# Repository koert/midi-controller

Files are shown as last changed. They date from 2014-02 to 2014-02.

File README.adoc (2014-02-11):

== DIY Midi controller

This is a project to create a custom MIDI controller based on:

* Teensy 3.1
* Pressure sensitive buttons made with anti static foam
* WS2812B LED's
* Nokia 5110 LCD display

=== Resources

==== Teensy
Website: http://www.pjrc.com/teensy
Shop: http://floris.cc/shop/en/8-teensy

==== LCD display
https://www.sparkfun.com/products/10168

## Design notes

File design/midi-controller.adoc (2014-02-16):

== Midi controller

=== Todo

* connect LED's, display pushed button
* buttons for octave up/down

=== Done

* design schematic pressure button in 4x4 matrix
* mount buttons on PCB
* display notes on LCD display
* note on/off with velocity
* pushbutton prototype - connect to Arduino
* send midi note to computer via Serial

=== Inspiration

http://jazarimusic.com/finally-a-diy-midi-controller-with-purpleheart/

==== Velocity and aftertouch

[quote, http://www.codetinkerhack.com/2013/01/how-to-add-velocity-aftertouch-midi.html]
____
1) Measuring Velocity sensitivity required to add timing mechanism to allow sufficient time to read the FSR sensor as Note will get pressed first and FSR sensor second. So before we can send the note we need to measure the FSR values. To implement this two arrays were introduced: one  remembers the Note that was pressed and acts as a buffer: noteChannelPressed and second remembers the milliseconds when the note was pressed: previousMillisChannel. After a delay of about 1 ms value of FSR is translated to a volume. (currently linear translation is done by simple mapping the range of FSR  to MIDI but you can experiment and see what suits most your FSR/location/mechanics, etc). And after that note with volume is sent to Midi. The functions implementing above are getNote() and sendChannelNotes()

2) Aftertouch was implemented (as well) based on FSR readings and handled by sendChannelExpression(). Effect is only kicks in after 1 second which is configured in expressionDelay constant. As aftertouch effect I've used midi modulation command as it is widely supported by all synth. It can be map to any other effect that your synth support.
____

=== Hardware

==== Multiplexer

http://www.conrad.nl/ce/nl/product/155668/Logic-IC-STMicroelectronics-HCF-4051-BEY-Soort-behuizing-DIP-16-Uitvoering-Multiplexer
3 bit selector for 8 in/out

http://www.conrad.nl/ce/nl/product/173320/CMOS-IC-Texas-Instruments-4067-Soort-behuizing-DIP-24-Uitvoering-Multiplexerdemultiplexer-16-analogedigitale-kanalen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
4 bit selector for 16 in/out

==== Other

Arduino Leonardo

* http://www.conrad.nl/ce/nl/product/046518/Arduino-Leonardo-incl-USB-kabel?ref=list
* https://www.youtube.com/watch?v=aaGbciiM_G0
* https://iprototype.nl/products/arduino/boards/leonardo-no-headers

LED  WS2812

* http://mikrocontroller-praxis.de/de/Display-Optoelektronik/LED/LED-RGB/WS2812-5050-RGB-LED-with-Integrated-Driver-Chip-1PCS.html

LED  WS2812B

* http://www.aliexpress.com/item/WS2812B-4pins-5050-SMD-W-WS2811-Individually-Addressable-Digital-RGB-LED-Chip/1416686122.html

Teensy

* http://www.pjrc.com/teensy/
* http://floris.cc/shop/en/8-teensy

Buttons

* https://www.sparkfun.com/products/7835

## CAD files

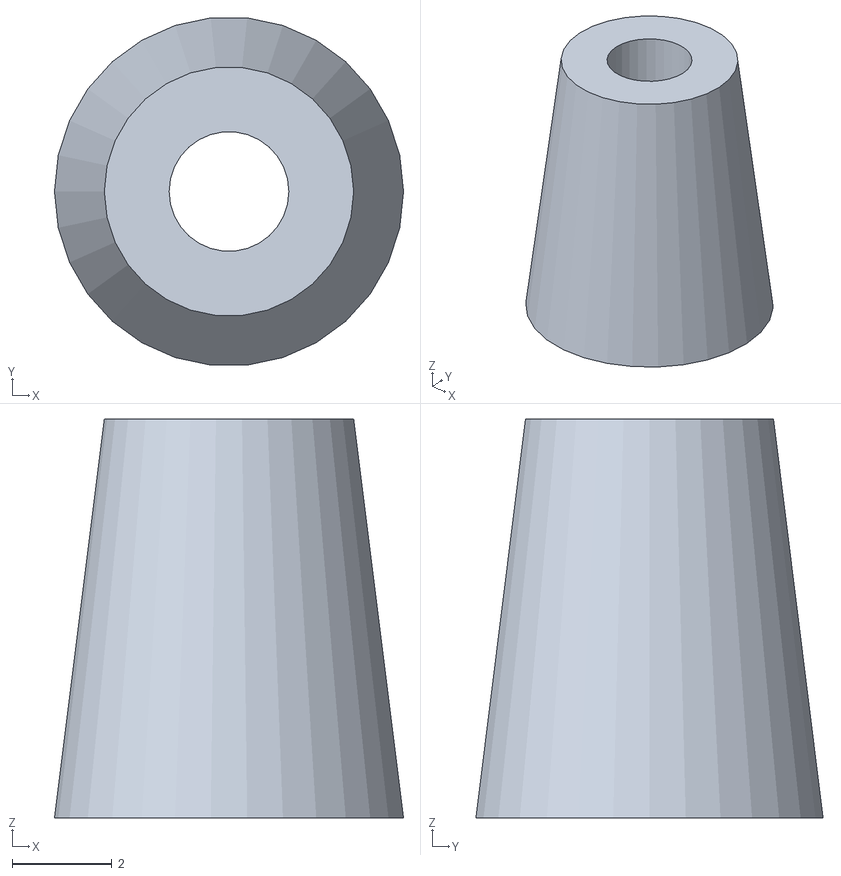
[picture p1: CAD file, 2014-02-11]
design/button-foam4.stl
7.00 x 6.96 x 8.00

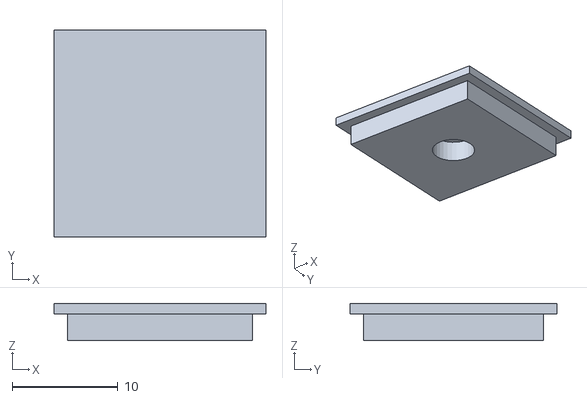
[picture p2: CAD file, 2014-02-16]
design/switch-foam-combo/button-grid-top.stl
20.0 x 19.5 x 3.50

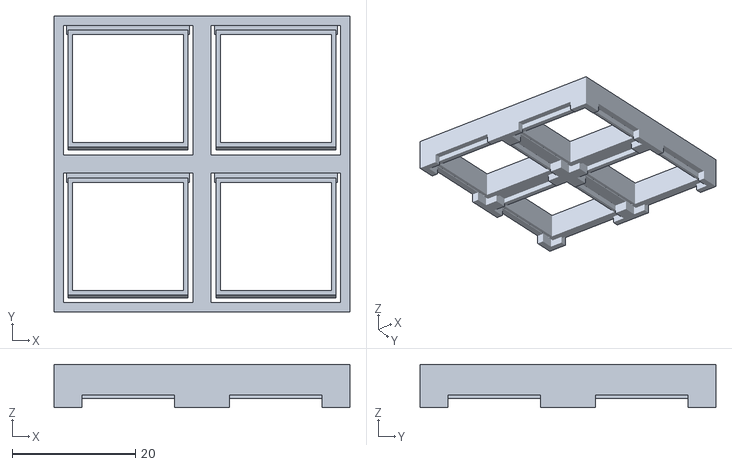
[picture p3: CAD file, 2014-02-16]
design/switch-foam-combo/button-grid.stl
48.0 x 48.0 x 7.00

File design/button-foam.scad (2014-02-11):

outerSize = 20;
innerSize = 18;
topHeight = 4;
baseHeight = 5;
foamWidth = 5;
foamHeight = 1.0;
spaceY = 2;
thickness = 1;
margin = 1.2;
tightMargin = 0.5;

module top() {
  $fn=100;
  $fs=1;
  translate([0, 0, baseHeight + spaceY])
  difference() {
    translate([0, 0, topHeight/2])
    cube([outerSize, outerSize, topHeight], center=true);
    translate([0, 0, topHeight/2-thickness])
    cube([innerSize, innerSize, topHeight], center=true);
  }

}

module base() {
  $fn=100;
  $fs=1;
  translate([0, 0, baseHeight/2])
  difference() {
    translate([0, 0, 0])
    cube([outerSize, outerSize, baseHeight], center=true);
    translate([0, 0, 0])
    cube([innerSize, innerSize, baseHeight+1], center=true);
  }

}

module buttonTop() {
  $fn=100;
  $fs=1;
  innerHeight = baseHeight - foamHeight - tightMargin;
  translate([0, 0, thickness])
  union() {
    translate([0, 0, thickness/2])
    cube([outerSize, outerSize, thickness], center=true);
    translate([0, 0, -innerHeight/2])
    cube([innerSize-tightMargin, innerSize-tightMargin, innerHeight], center=true);
  }
}

module buttonBottom() {
  $fn=100;
  $fs=1;
  height = baseHeight;
  innerHeight = baseHeight - foamHeight + margin;  
  translate([0, 0, 0])
  difference() {
    union() {
      translate([0, 0, baseHeight/2])
      cube([outerSize, outerSize, baseHeight], center=true);
      translate([0, 0, thickness+thickness/2])
      cube([outerSize/2, outerSize+thickness, thickness], center=true);
      translate([0, 0, thickness+thickness/2])
      cube([outerSize+thickness, outerSize/2, thickness], center=true);
    }
    translate([0, innerSize/2-foamWidth/2, height/2])
    cube([innerSize, foamWidth, height+thickness+1], center=true);
    translate([0, -innerSize/2+foamWidth/2, height/2])
    cube([innerSize, foamWidth, height+thickness+1], center=true);
    translate([0, 0, height/2])
    cube([innerSize, innerSize-foamWidth*2-thickness*2, height+thickness+1], center=true);
    translate([0, 0, innerHeight/2+foamHeight])
    cube([innerSize, innerSize, innerHeight+0.01], center=true);
  }

}

module buttonMountInner(innerWidth, width, height) {
  innerWidth2 = innerWidth + thickness + margin;
    union() {
	    translate([0, 0, height/2])
	    cube([innerWidth, innerWidth, height+1], center=true);
	    #translate([0, 0, thickness*2])
	    cube([innerWidth2, outerSize/2 + margin, thickness*4], center=true);
	    translate([0, 0, thickness*2])
	    cube([outerSize/2 + margin, innerWidth2, thickness*4], center=true);
	    translate([0, 0, thickness-0.5])
	    cube([innerWidth-thickness*2, width+1, thickness*2], center=true);
	    translate([0, 0, thickness-0.5])
	    cube([width+1, innerWidth-thickness*2, thickness*2], center=true);
    }
}

module buttonMount() {
  width = outerSize + thickness*6;
  spacing = 2.0;
  totalWidth = outerSize*2 + spacing*4;
  height = baseHeight;
  innerWidth = outerSize + margin;
  innerWidth2 = outerSize + thickness*2 + margin;
  translate([0, 0, -thickness*4])
  difference() {
    translate([0, 0, height/2])
    cube([totalWidth, totalWidth, height], center=true);

    translate([outerSize/2+spacing, outerSize/2+spacing, 0])
    buttonMountInner(innerWidth, width, height);

    translate([-outerSize/2-spacing, outerSize/2+spacing, 0])
    buttonMountInner(innerWidth, width, height);

    translate([outerSize/2+spacing, -outerSize/2-spacing, 0])
    buttonMountInner(innerWidth, width, height);

    translate([-outerSize/2-spacing, -outerSize/2-spacing, 0])
    buttonMountInner(innerWidth, width, height);
  }
}

module bottomSupport() {
  $fn = 30;
  difference() {
    cylinder(h = 8, r1 = 3.5, r2 = 2.5, center = true);
    cylinder(h = 9, r = 1.2, center = true);
  }
}

*top();
*base();

*buttonTop();

*translate([0, 0, -10])
buttonBottom();

*translate([45, 0, -10])
buttonMount();

translate([0, 0, -10])
bottomSupport();

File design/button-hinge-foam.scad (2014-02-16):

capOuterWidth = 20;
capOuterHeight = 7;
buttonMargin = 2;
holeRadius = 5/2;
holeHeight = 2.5;
wallThickness = 1;
tightMargin = 0.5;
margin = 1;
foamWidth = 5;
foamHeight = 1.0;

module capTop() {
  $fn = 30;
  innerWidth = capOuterWidth - wallThickness*2 - tightMargin;
  ceilingHeight = holeHeight;
  //translate([0, 0, capOuterHeight/2])
  union() {
    translate([0, 0, ceilingHeight/2+wallThickness/2])
    cube([capOuterWidth, capOuterWidth-wallThickness/2, wallThickness], center=true);
    translate([0, 0, 0])
    difference() {
      cube([innerWidth, innerWidth-wallThickness/2, ceilingHeight], center=true);
      translate([0, 0, holeHeight-margin/2-ceilingHeight])
      cylinder(h = holeHeight+margin, r = holeRadius, center = true);
    }
  }
}


module inner(innerWidth) {
  union() {
    translate([0, 0, 0])
    cube([innerWidth, innerWidth, capOuterHeight+margin], center=true);

    translate([0, 0, -capOuterHeight+wallThickness*2])
    cube([capOuterWidth*0.75, capOuterWidth+wallThickness*5, capOuterHeight], center=true);
    translate([0, 0, -capOuterHeight+wallThickness*2])
    cube([capOuterWidth+wallThickness*5, capOuterWidth*0.75, capOuterHeight], center=true);
  }
}


module grid() {
  $fn = 30;
  buttonGridSize = capOuterWidth + buttonMargin*2;
  gridWidth = buttonGridSize * 2;
  gridHeight = buttonGridSize * 2;
  innerWidth = capOuterWidth + margin;
  ceilingHeight = holeHeight + wallThickness;
  union() {
	  translate([0, 0, capOuterHeight/2])
	  difference() {
	    translate([0, 0, 0])
	    cube([gridWidth, gridWidth, capOuterHeight], center=true);
	
	    translate([-buttonGridSize/2, buttonGridSize/2, 0])
	    inner(innerWidth);
	    translate([buttonGridSize/2, buttonGridSize/2, 0])
	    inner(innerWidth);
	    translate([-buttonGridSize/2, -buttonGridSize/2, 0])
	    inner(innerWidth);
	    translate([buttonGridSize/2, -buttonGridSize/2, 0])
	    inner(innerWidth);
	 }

    translate([-buttonGridSize/2, buttonGridSize/2, 0])
    capBottom();

    translate([buttonGridSize/2, buttonGridSize/2, 0])
    capBottom();

    translate([-buttonGridSize/2, -buttonGridSize/2, 0])
    capBottom();

    translate([buttonGridSize/2, -buttonGridSize/2, 0])
    capBottom();
 }
}

module capBottom() {
  $fn = 30;
  size = capOuterWidth-tightMargin;
  innerWidth = capOuterWidth - wallThickness*2;
  height = capOuterHeight - wallThickness - tightMargin;
  translate([0, 0, capOuterHeight-height/2])
  difference() {
    union() {
      translate([0, -size/2, -height/2])
      rotate(a = [90, 0, 90])
      linear_extrude(height = size, center = true)
      polygon([[0,height/4],[size,0],[size,height], [wallThickness, height]], convexity = N);

      translate([0, capOuterWidth/2, -height/2+wallThickness/2])
      cube([capOuterWidth, wallThickness*2, wallThickness], center=true);
    }
    translate([0, wallThickness/2, 0])
    cube([innerWidth, innerWidth-wallThickness/2, height+margin], center=true);
  }
}

intersection() {
//translate([-3, -3, 0])
//cube([capOuterWidth*1.5, capOuterWidth*1.5, capOuterHeight*2]);

translate([0, 0, 0])
grid();
}

*translate([0, 0, 20])
capTop();

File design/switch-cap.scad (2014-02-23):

capOuterWidth = 20;
capOuterHeight = 7;
holeRadius = 3.5/2;
holeHeight = 2.5;
wallThickness = 1;
tightMargin = 0.5;
margin = 1;

module cap() {
  $fn = 30;
  innerWidth = capOuterWidth - wallThickness;
  ceilingHeight = holeHeight + wallThickness;
  translate([0, 0, capOuterHeight/2])
  difference() {
    translate([0, 0, 0])
    cube([capOuterWidth, capOuterWidth, capOuterHeight], center=true);
    translate([0, 0, -ceilingHeight])
    cube([innerWidth, innerWidth, capOuterHeight], center=true);
    translate([0, 0, capOuterHeight/2-ceilingHeight+holeHeight/2])
    cylinder(h = holeHeight+1, r = holeRadius, center = true);
  }
}

module capTop() {
  $fn = 30;
  innerWidth = capOuterWidth - wallThickness*2 - tightMargin;
  ceilingHeight = holeHeight;
  //translate([0, 0, capOuterHeight/2])
  union() {
    translate([0, 0, ceilingHeight/2+wallThickness/2])
    cube([capOuterWidth, capOuterWidth, wallThickness], center=true);
    translate([0, 0, 0])
    difference() {
      cube([innerWidth, innerWidth, ceilingHeight], center=true);
      translate([0, 0, holeHeight-margin/2-ceilingHeight])
      cylinder(h = holeHeight+margin, r = holeRadius, center = true);
    }
  }
}

module capBottom() {
  $fn = 30;
  innerWidth = capOuterWidth - wallThickness*2;
  height = capOuterHeight - wallThickness - tightMargin;
  translate([0, 0, capOuterHeight/2])
  difference() {
    union() {
      translate([0, 0, 0])
      cube([capOuterWidth, capOuterWidth, height], center=true);
      translate([0, 0, wallThickness/2])
      cube([capOuterWidth/2, capOuterWidth+wallThickness*2, wallThickness], center=true);
      translate([0, 0, wallThickness/2])
      cube([capOuterWidth+wallThickness*2, capOuterWidth/2, wallThickness], center=true);
    }
    translate([0, 0, 0])
    cube([innerWidth, innerWidth, height+margin], center=true);
  }
}

*rotate(a = [0, 180, 0])
cap();

translate([0, 0, 5])
rotate(a = [0, 180, 0])
capTop();

*translate([0, 0, -5])
capBottom();

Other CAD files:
design/switch-foam-combo/button-grid1.stl
design/switch-foam-combo/button-grid.scad
design/switch-foam-combo/button-hinge-grid.scad

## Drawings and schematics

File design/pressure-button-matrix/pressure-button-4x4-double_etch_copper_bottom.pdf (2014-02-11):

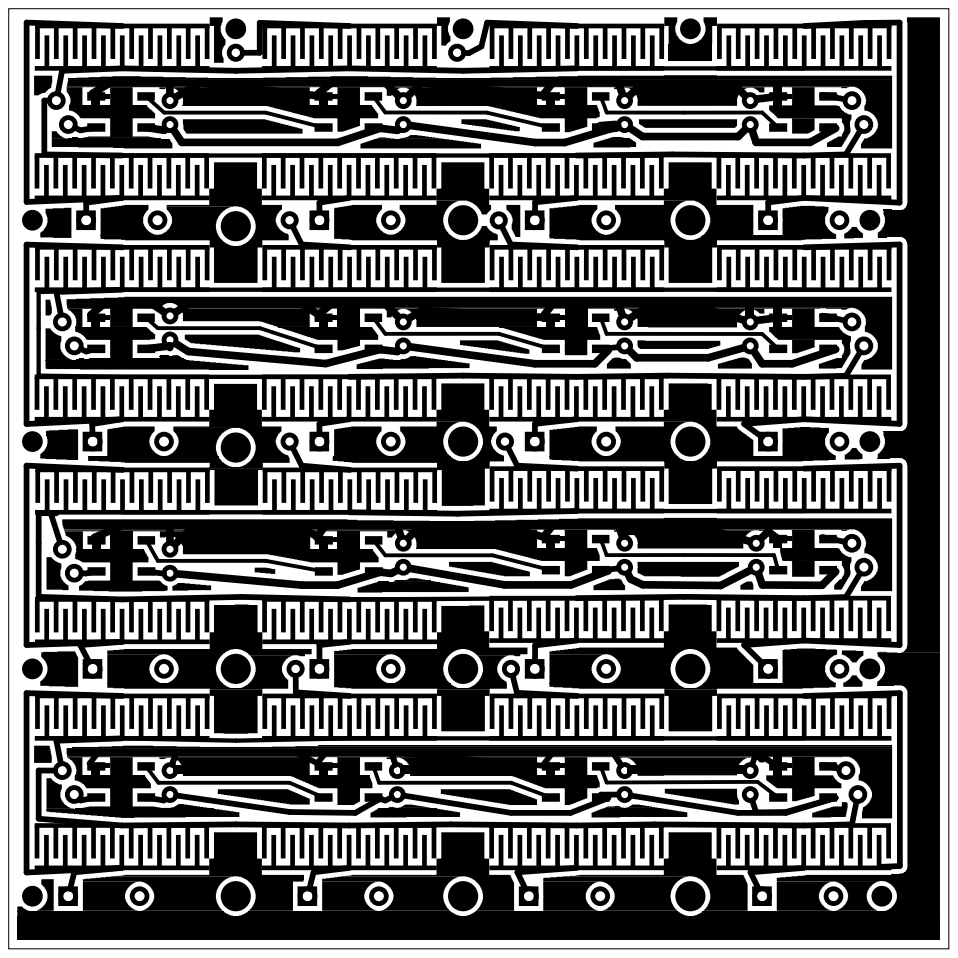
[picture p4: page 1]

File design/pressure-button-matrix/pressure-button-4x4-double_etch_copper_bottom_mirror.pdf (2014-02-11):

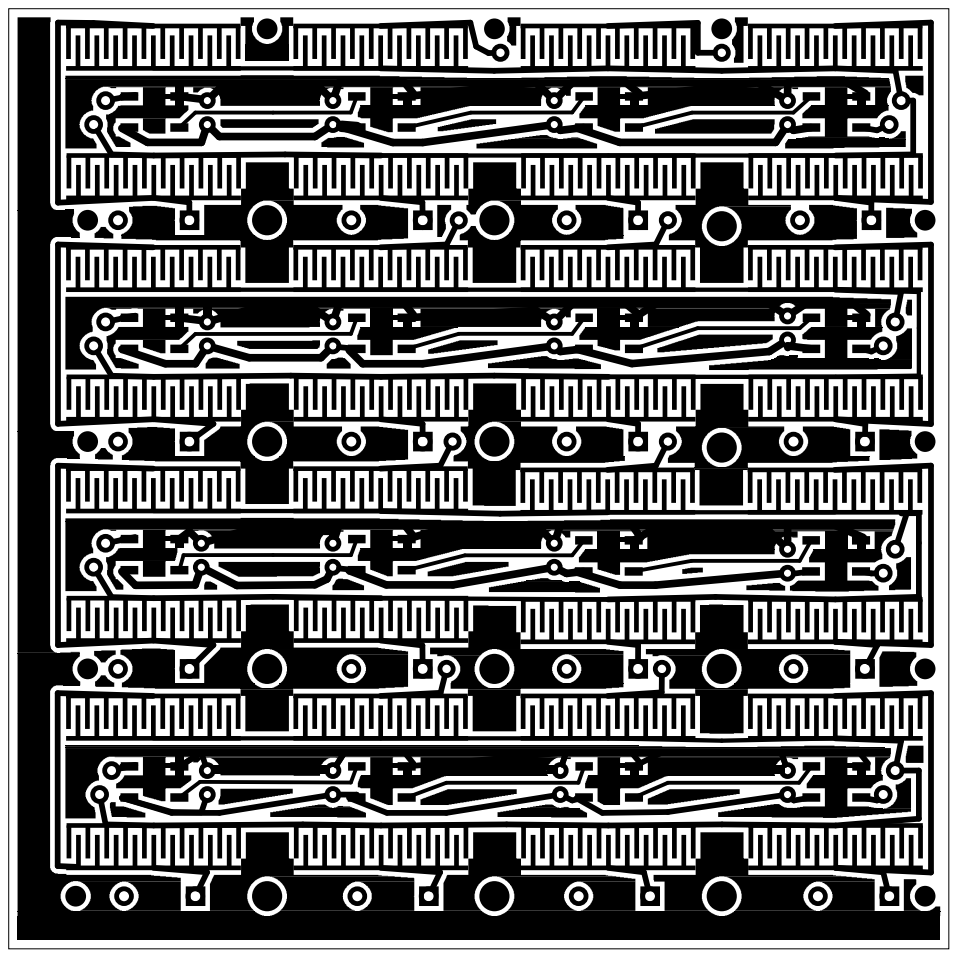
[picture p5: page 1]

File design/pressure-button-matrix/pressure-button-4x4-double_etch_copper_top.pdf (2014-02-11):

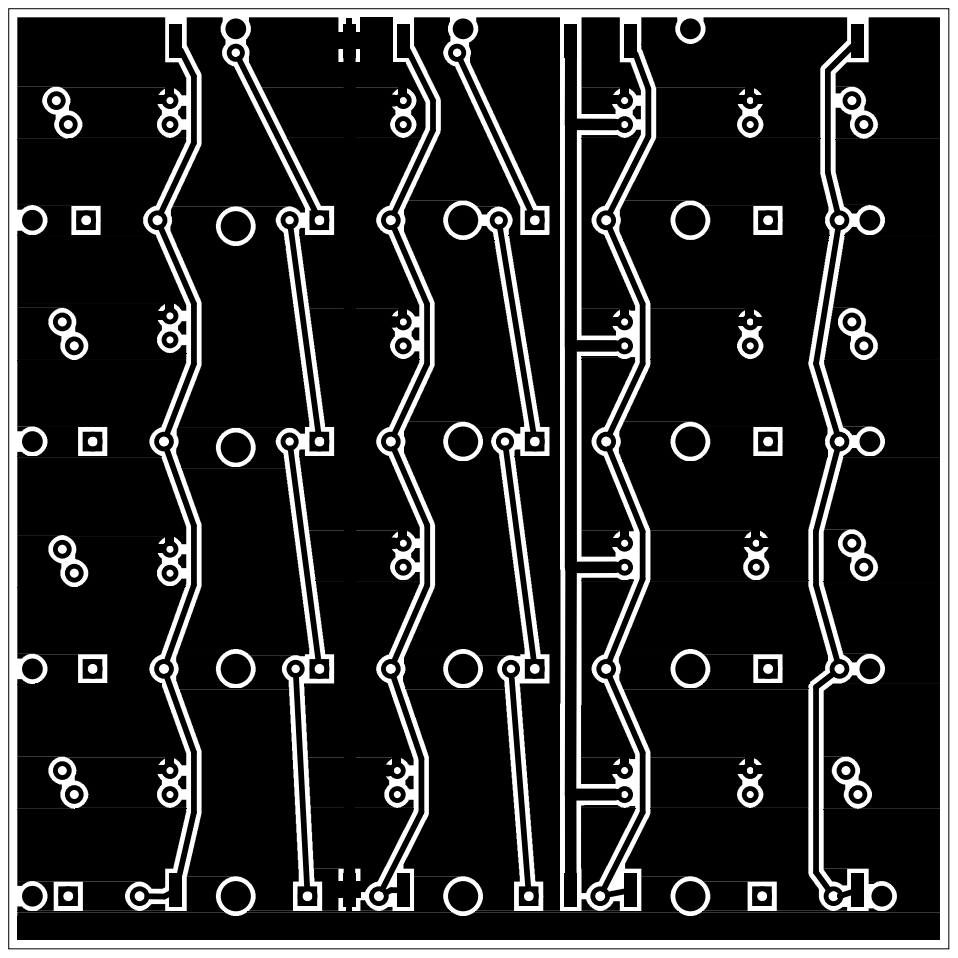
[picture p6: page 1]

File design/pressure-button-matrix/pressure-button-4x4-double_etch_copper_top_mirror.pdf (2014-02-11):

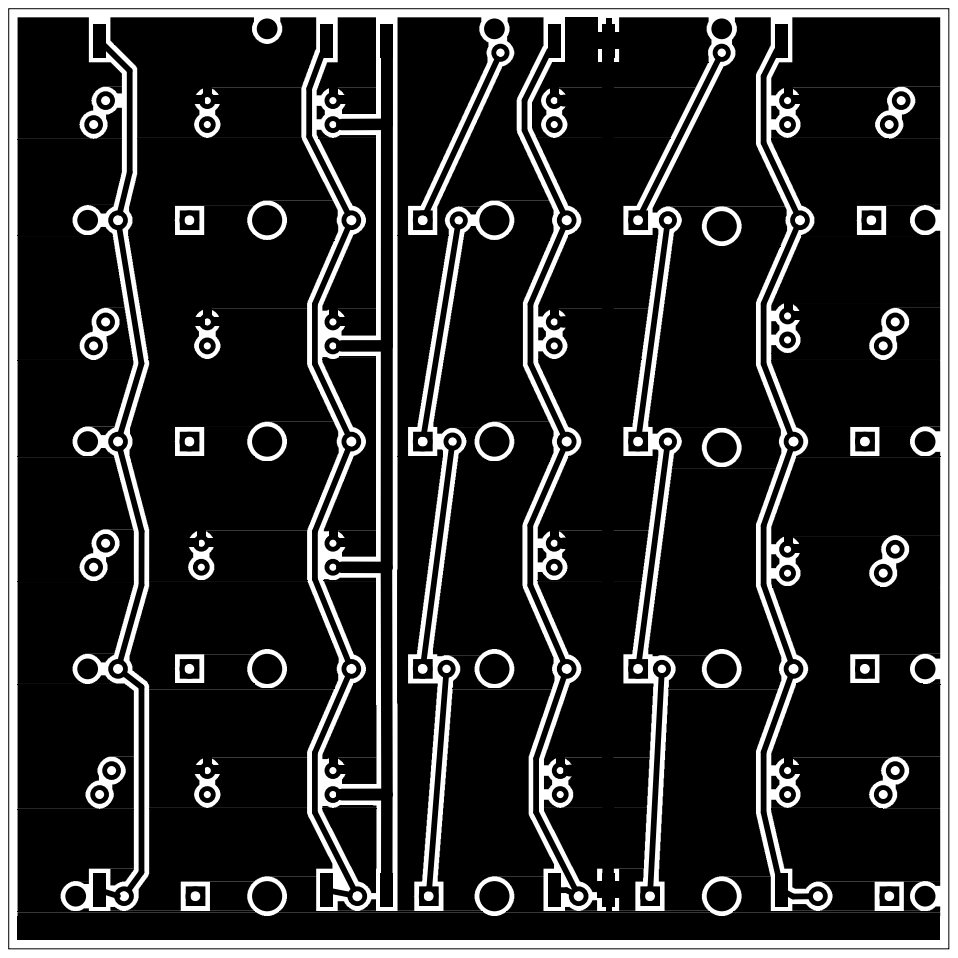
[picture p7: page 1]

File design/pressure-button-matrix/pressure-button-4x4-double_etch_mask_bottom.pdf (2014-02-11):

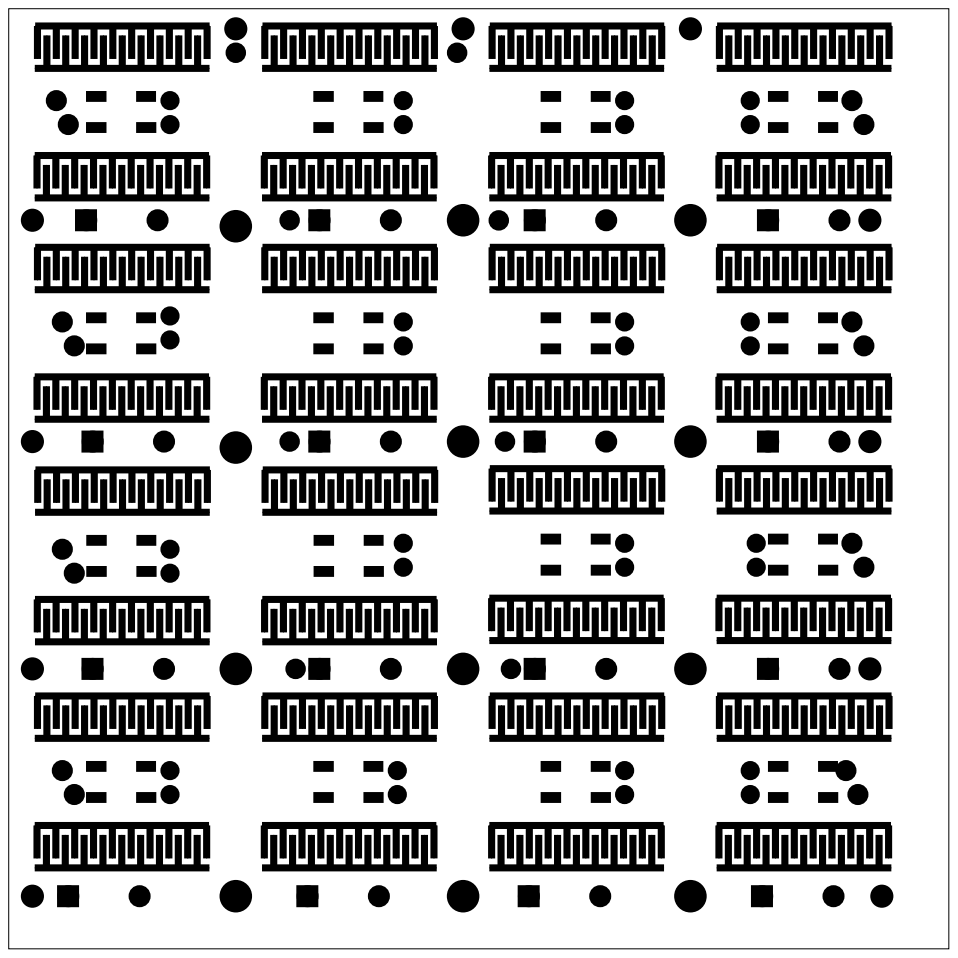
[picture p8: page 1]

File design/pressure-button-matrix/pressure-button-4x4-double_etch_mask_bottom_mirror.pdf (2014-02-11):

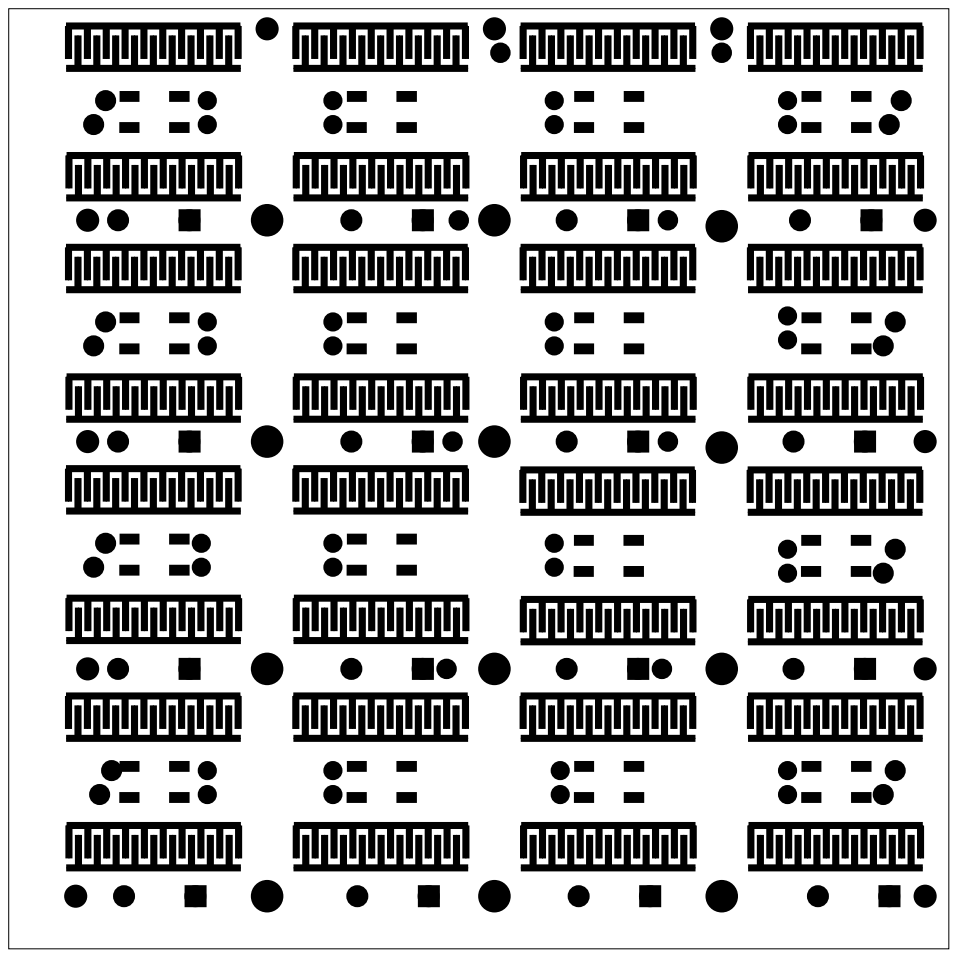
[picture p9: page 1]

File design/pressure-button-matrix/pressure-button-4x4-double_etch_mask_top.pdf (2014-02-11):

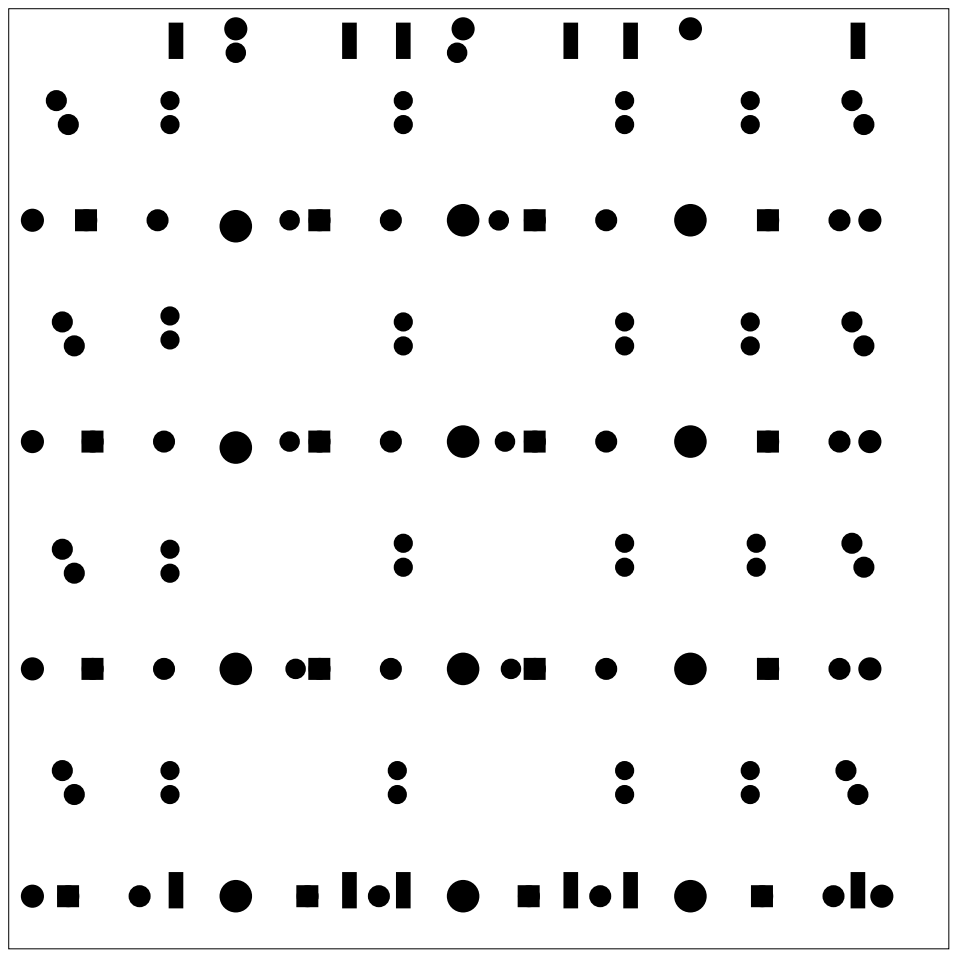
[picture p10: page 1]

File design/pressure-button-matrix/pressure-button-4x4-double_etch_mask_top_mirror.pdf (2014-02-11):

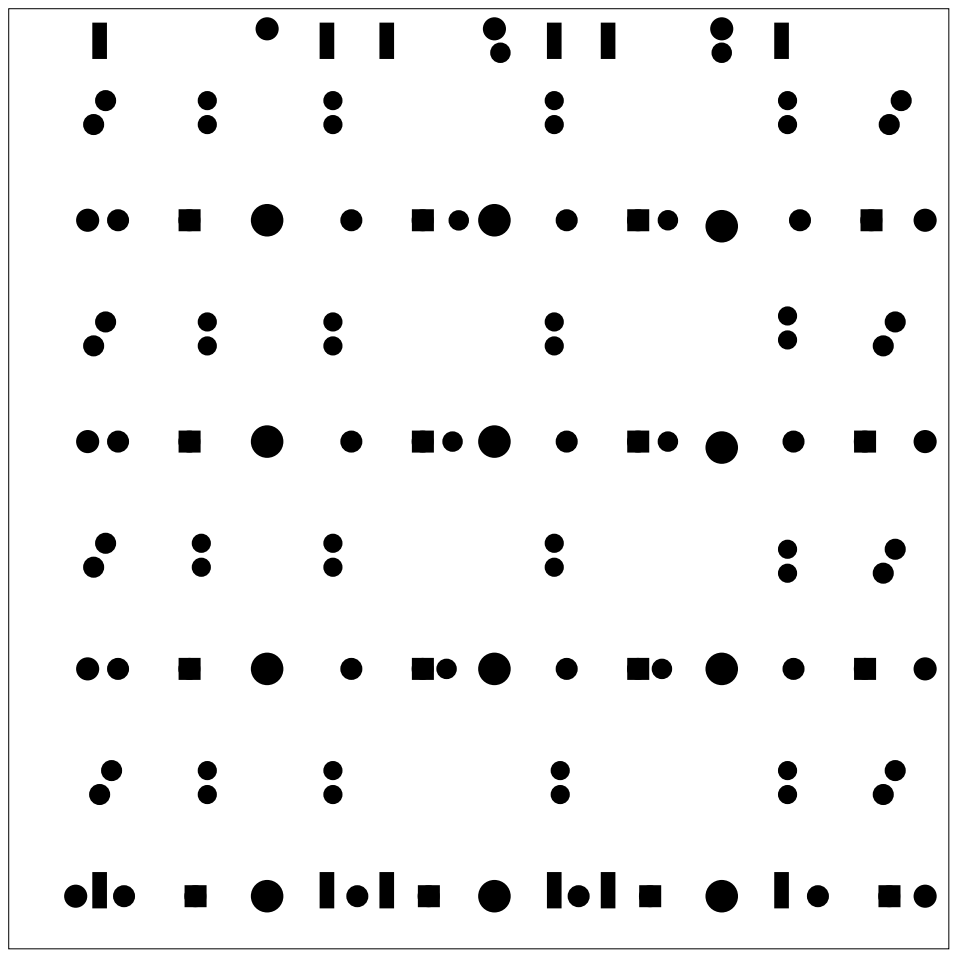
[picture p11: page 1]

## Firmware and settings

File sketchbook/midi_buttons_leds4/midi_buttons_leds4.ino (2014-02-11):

/* Buttons to USB MIDI Example

   You must select MIDI from the "Tools > USB Type" menu

   To view the raw MIDI data on Linux: aseqdump -p "Teensy MIDI"

   This example code is in the public domain.
*/

#include <Bounce.h>
#include <Adafruit_NeoPixel_teensy.h>
#include <Adafruit_GFX.h>
#include <Adafruit_PCD8544.h>



// the MIDI channel number to send messages
const int channel = 1;
const int numberOfRows = 2;
const int numberOfColumns = 2;

#define LED_STRIP_PIN 21
#define NUMBER_OF_PIXELS 8
Adafruit_NeoPixel strip = Adafruit_NeoPixel(NUMBER_OF_PIXELS, LED_STRIP_PIN, NEO_GRB + NEO_KHZ800);

// pin 12 - Serial clock out (SCLK)
// pin 11 - Serial data out (DIN)
// pin 10 - Data/Command select (D/C)
// pin 9 - LCD chip select (CS)
// pin 8 - LCD reset (RST)
Adafruit_PCD8544 display = Adafruit_PCD8544(12, 11, 10, 9, 8);

const int ledPin = 13;

int rowPins[] = {0, 1}; // analog input of row
int columnPins[] = {0, 1}; // digital output of column activation feed

int buttonNote[] = {60, 64, 63, 67, 67, 71, 1, 1, 1, 1, 1, 1, 1, 1, 1, 1};
int buttonState[] = {0, 0, 0, 0, 0, 0, 0, 0, 0, 0, 0, 0, 0, 0, 0, 0};
int buttonValue[] = {0, 0, 0, 0, 0, 0, 0, 0, 0, 0, 0, 0, 0, 0, 0, 0};
unsigned long previousTime[] = {0, 0, 0, 0, 0, 0, 0, 0, 0, 0, 0, 0, 0, 0, 0, 0};

void setup() {  
  pinMode(ledPin, OUTPUT);
  digitalWrite(ledPin, HIGH);   // set the LED on
  
  initializeColumnPins();
  initializeDisplay();
  
  strip.begin();
  strip.show(); // Initialize all pixels to 'off'
}

void loop() {

  int columnIndex;
  for (columnIndex=0; columnIndex<numberOfColumns; columnIndex++) {
    digitalWrite(columnPins[columnIndex], HIGH); // activate column

    int rowIndex;
    for (rowIndex=0; rowIndex<numberOfRows; rowIndex++) {
      int buttonIndex = rowIndex * numberOfColumns + columnIndex;
      
      int val = analogRead(rowPins[rowIndex]);
    
      if (buttonState[buttonIndex] == 0) {
        if (val > 40) {
          display.clearDisplay();
          display.setCursor(0,0);
          display.print("val1: ");
          display.print(val);
          display.print(" ");
          display.println(buttonIndex);
          display.display();
    
          previousTime[buttonIndex] = micros();
          buttonValue[buttonIndex] = val;
          buttonState[buttonIndex] = 1;
        }
      } else if (buttonState[buttonIndex] == 1) {
        if (val < 35) {
          buttonValue[buttonIndex] = 0;
          buttonState[buttonIndex] = 0;
        } else if (val > 300) {
          display.setCursor(0,10);
          display.print("val2: ");
          display.println(val);
          unsigned long currentTime = micros();
          unsigned long elapsedTime = elapsed(previousTime[buttonIndex], currentTime);
          unsigned long velocity = (val - buttonValue[buttonIndex]) * 1000 / elapsedTime;
          if (velocity > 127) {
            velocity = 127;
          }
          display.setCursor(0,20);
          display.print("velocity: ");
          display.println(velocity);
          display.display();
          noteOn(buttonIndex, velocity);
          buttonState[buttonIndex] = 2;
        }
      } else if (buttonState[buttonIndex] == 2) {
        if (val < 20) {
          noteOff(buttonIndex);
          buttonValue[buttonIndex] = 0;
          buttonState[buttonIndex] = 0;
        } else {
          display.setCursor(0,30);
          display.print("val4: ");
          display.fillRect(35, 30, 30, 10, WHITE);
          display.setCursor(7*5,30);
          display.println(val);
          display.display();
          unsigned long velocity = val/2;
          if (velocity > 127) {
            velocity = 127;
          }
          usbMIDI.sendAfterTouch(velocity, channel);
        }      
      }
    }      
    digitalWrite(columnPins[columnIndex], LOW); // deactivate column


  }
  
  // MIDI Controllers should discard incoming MIDI messages.
  // http://forum.pjrc.com/threads/24179-Teensy-3-Ableton-Analog-CC-causes-midi-crash
  while (usbMIDI.read()) {
    // ignore incoming messages
  }
}

void noteOn (int button) {
    digitalWrite(ledPin, HIGH);    // set the LED off
    usbMIDI.sendNoteOn(buttonNote[button], 99, channel);
    strip.setPixelColor(button, strip.Color(0, 0, 100));
    strip.show();
}

void noteOn (int button, int velocity) {
    digitalWrite(ledPin, HIGH);    // set the LED off
    usbMIDI.sendNoteOn(buttonNote[button], velocity, channel);
    strip.setPixelColor(button, strip.Color(100, 0, 0));
    strip.setPixelColor(4, strip.Color(0, 0, 0));
    strip.setPixelColor(5, strip.Color(0, 0, 0));
    strip.setPixelColor(6, strip.Color(0, 0, 0));
    strip.setPixelColor(7, strip.Color(0, 0, 0));
    if (velocity > 25) {
      strip.setPixelColor(4, strip.Color(0, 100, 0));
    }
    if (velocity > 50) {
      strip.setPixelColor(5, strip.Color(0, 100, 0));
    }
    if (velocity > 75) {
      strip.setPixelColor(6, strip.Color(0, 100, 0));
    }
    if (velocity > 100) {
      strip.setPixelColor(7, strip.Color(0, 100, 0));
    }
    strip.show();
}

void noteOff (int button) {
    digitalWrite(ledPin, LOW);    // set the LED off
    usbMIDI.sendNoteOff(buttonNote[button], 0, channel);
    strip.setPixelColor(button, strip.Color(0, 0, 0));
    strip.show();
}

unsigned long elapsed(unsigned long previousTime, unsigned long currentTime) {
  unsigned long elapsedTime = currentTime - previousTime;
  if (previousTime < currentTime) {
    elapsedTime = currentTime - previousTime;
  } else {
    elapsedTime = 429497295 - previousTime + currentTime;
  }
  return elapsedTime;
}

void initializeColumnPins() {
  int i;
  for (i=0; i<numberOfColumns; i++) {
    pinMode(columnPins[i], OUTPUT);
  } 
}

void initializeDisplay() {
  display.begin();
  display.setContrast(55);
  display.clearDisplay();   // clears the screen and buffer
  display.setTextSize(1);
  display.setTextColor(BLACK);
  display.setCursor(0,0);
  display.println("MIDI");
  display.println("Controller");
  display.println("v0.1");
  display.display();
}

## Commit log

2014-02-02 added teensy code
2014-02-03 created PCB for Teensy with button matrix connections
    [midi-controller-teensy.fzz]
2014-02-03 added notes, design for button matrix
    [button-foam.scad, pressure-button-4x4-double.fzz]
2014-02-11 added alternative pressure sensitive design
    [alt-button-matrix.fzz, button-foam.scad, button-foam4.stl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]
2014-02-16 added grid for switches
    [alt-button-matrix.fzz, button-grid-top.stl, button-grid.scad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]
2014-02-23 refined button grid with hinge
    [button-hinge-grid.scad, switch-cap.scad]
